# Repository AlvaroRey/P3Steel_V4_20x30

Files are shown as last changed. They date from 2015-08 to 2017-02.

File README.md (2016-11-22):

# P3Steel_V4_20x30
 
Version 4.0 (By Alvaro Rey and Daniel Torres) From P3steel by [irobri](http://www.thingiverse.com/thing:157303) with the listed changes:

* The extruder no longer hits the Z axis top bracket
* Y axis belt tensioner ( that may be placed printed or metallic )
* Weight reduction cutting as much material as possible
* Holes to bolt the PSU to the frame
* Electronics as high as possible so that the LCD cables are well hidden
* Holes in the top bracket of the Z axis to position bearing
* Holes in the top bracket of the Z axis to place spool holder
* Axis movable to lose the least footprint as posible
* Y axis uses 2020 profile, less pieces, more easy to install, less wieght, less price
* Y axis bed it's suitable to install 20x20 heated beds or 20x30 heated beds
* The hole for the motor connector has been enlarged, allowing installation of engines below 70 OZ
* Bed with option for 3 or 4 bearings
* Bed with choice of 4 or 3 leveling points
* Holes for Zip ties added to the main frame
* The Y-Axis rods have been changed, now uses 10mm rods and LM10UU lineal Bearings. We recomended to use aluminum beds for Y axis.
* We test aluminum frame too in 3mm. It works just the same
* 20x30 Frame - the Y-axis 10mm smooth rods should now be 510mm long

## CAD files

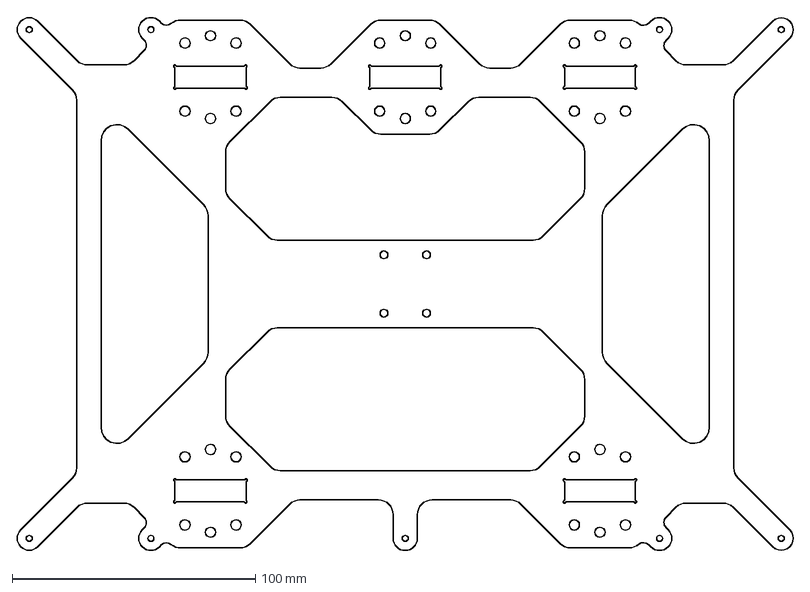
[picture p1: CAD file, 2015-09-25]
Bed_20x30_V4.DXF
319.7 x 220.0 mm

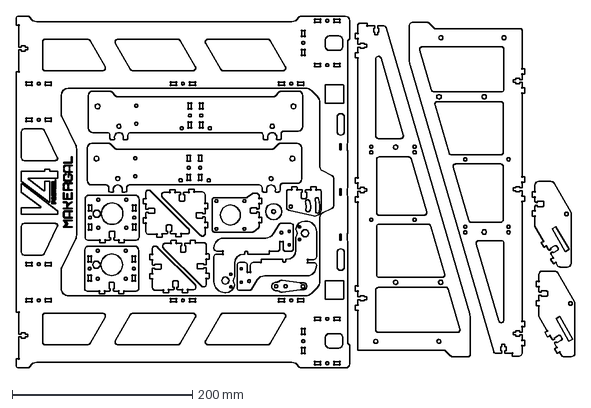
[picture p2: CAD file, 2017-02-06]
BluePrints_Planos/SEP2016/Frame_P3SteelV4_SEP2016.dxf
619.6 x 390.0 mm

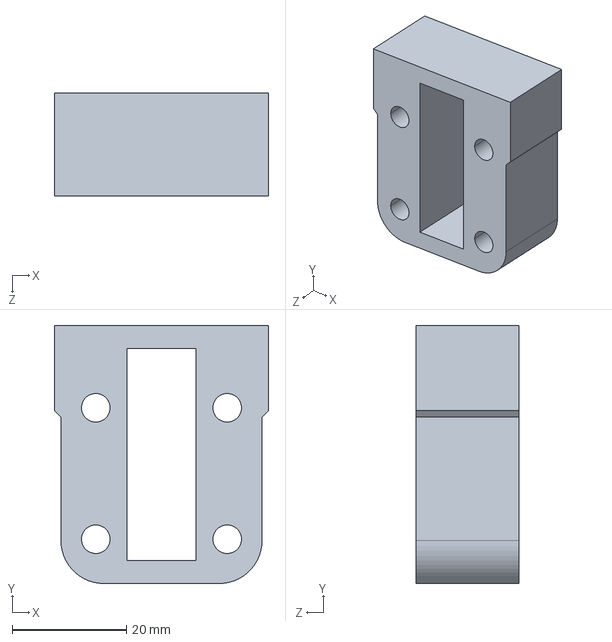
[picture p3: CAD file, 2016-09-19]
STLs/Extrusor - Separador.STEP
37.5 x 45.1 x 18.0 mm

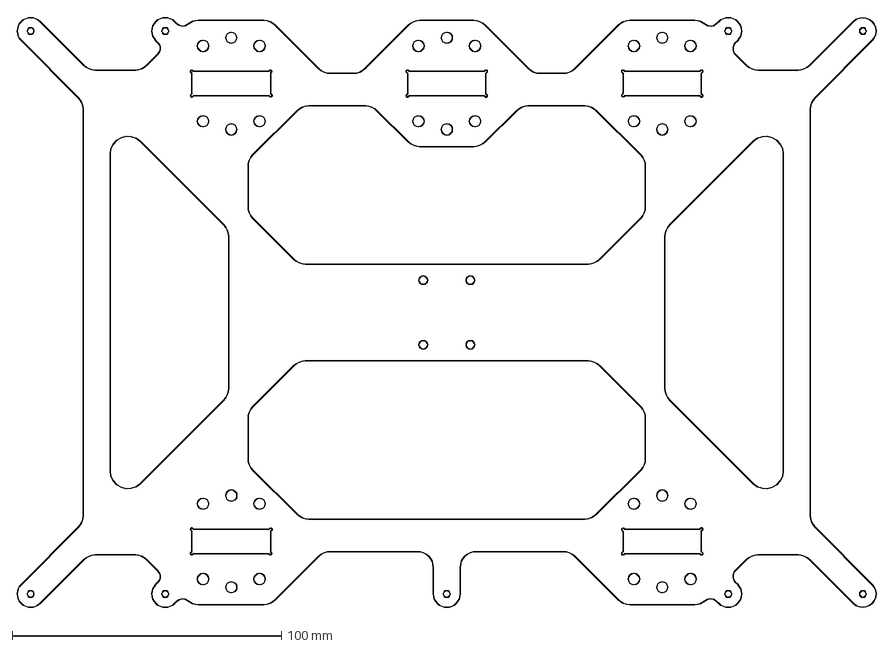
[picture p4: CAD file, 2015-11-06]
BluePrints_Planos/FEB2016/P3Steel_Bed_V4_20x30.DXF
319.7 x 220.0 mm

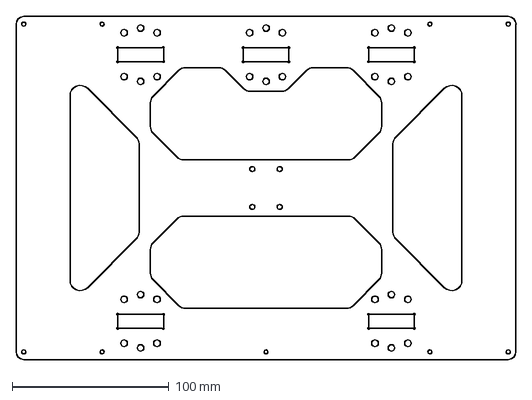
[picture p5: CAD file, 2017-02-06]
BluePrints_Planos/SEP2016/Base_P3Steel_SEP2016_ALUMINIO 4mm.DXF
318.9 x 218.9 mm

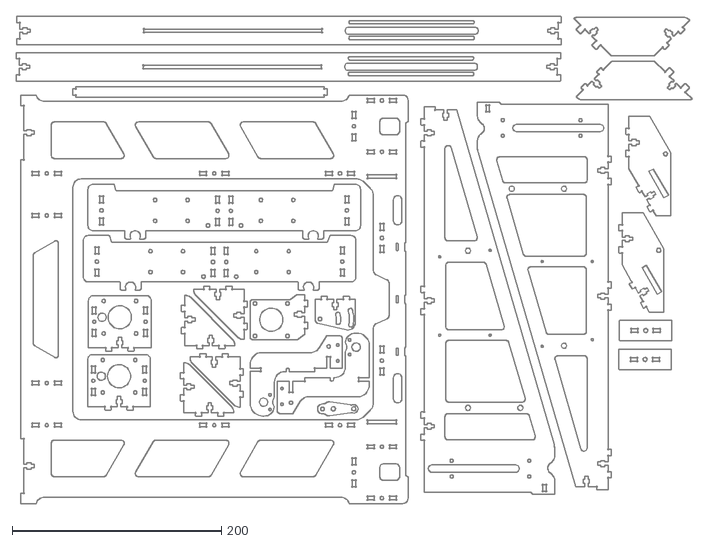
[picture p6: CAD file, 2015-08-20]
P3Steel_V4(2015)_20x30.dxf
645.5 x 465.0

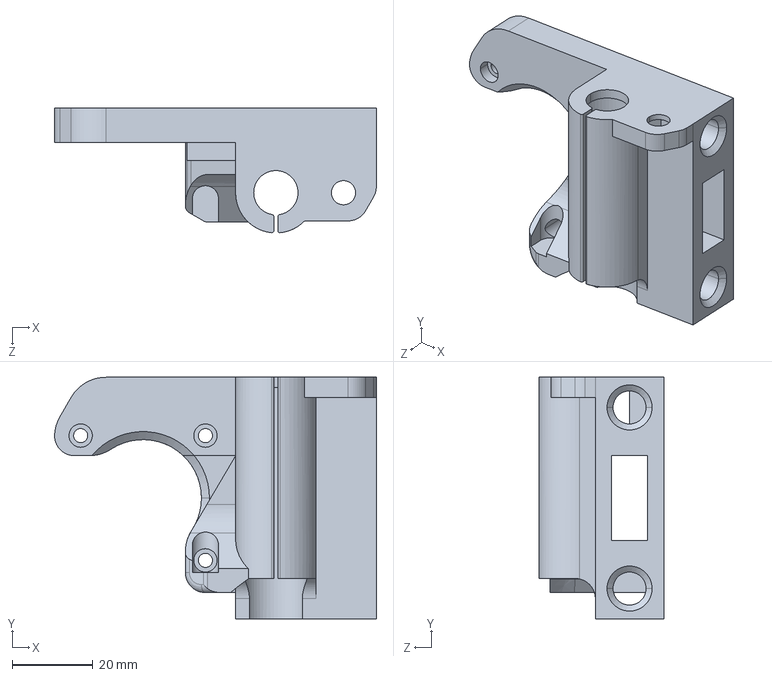
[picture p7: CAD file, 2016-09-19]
STLs/Eje X - Soporte Motor M5.STEP
80.0 x 60.0 x 30.9 mm

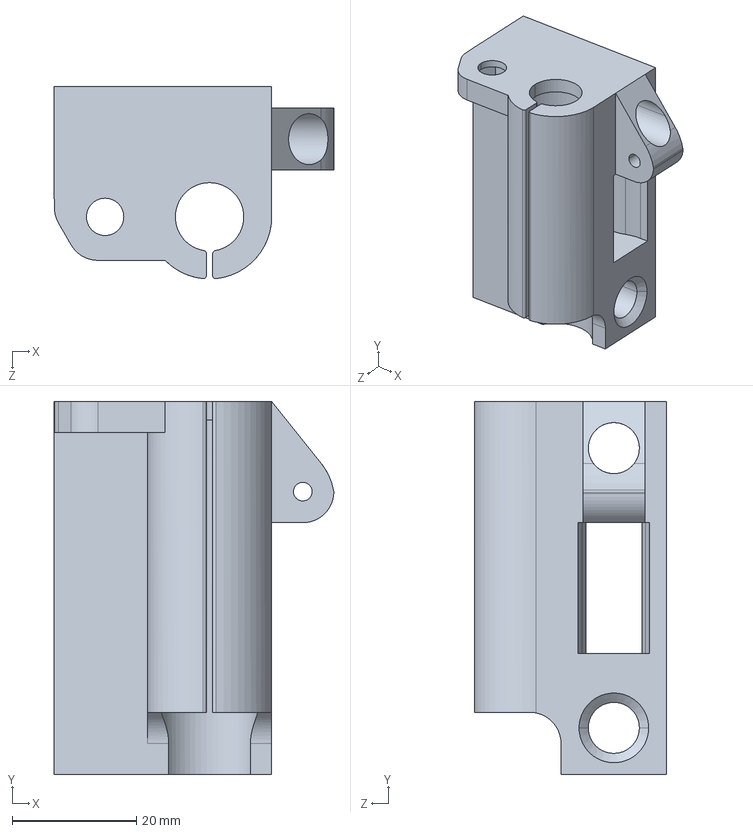
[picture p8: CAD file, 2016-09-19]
STLs/Eje X - Soporte Tensor M5.STEP
45.0 x 60.0 x 30.9 mm

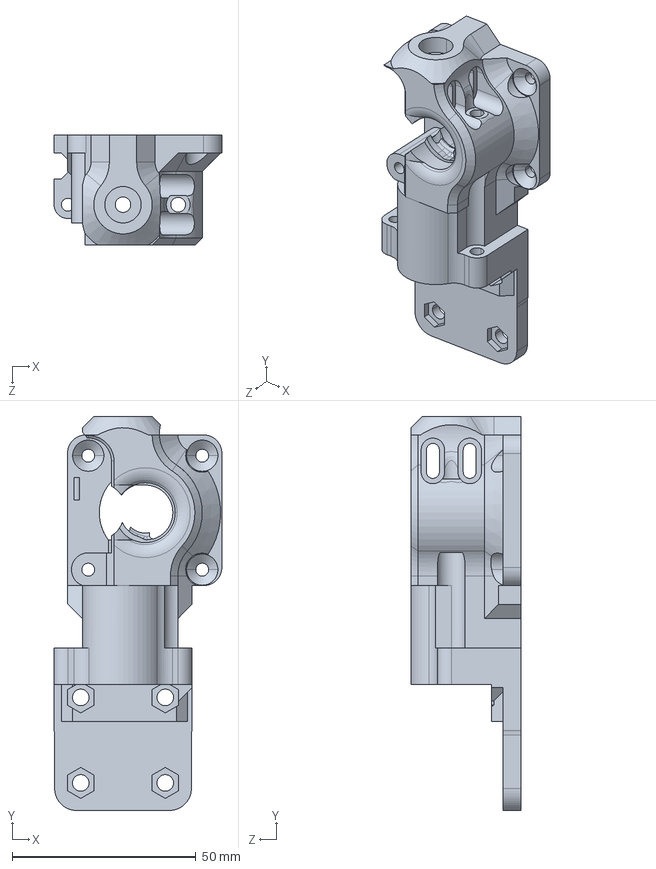
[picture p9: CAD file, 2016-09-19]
STLs/Extrusor - Cuerpo Extruder.STEP
45.7 x 107.2 x 30.0 mm

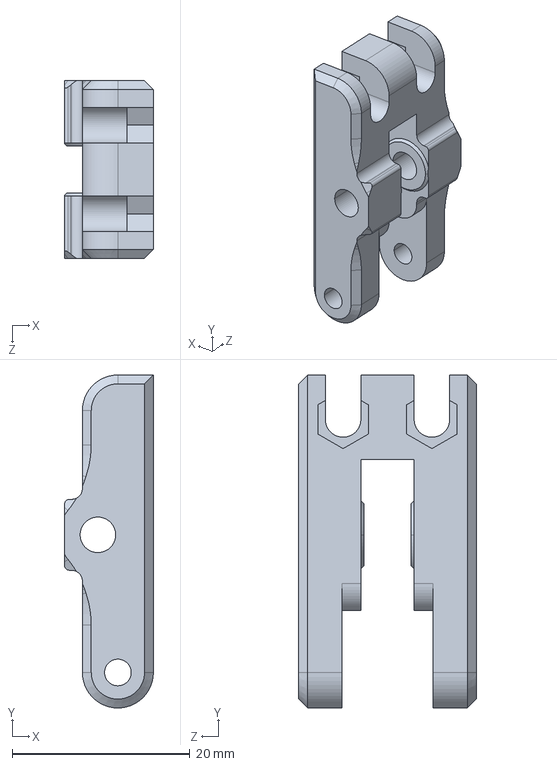
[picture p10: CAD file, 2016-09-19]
STLs/Extrusor - Tensor Filamento.STEP
10.0 x 37.5 x 20.0 mm

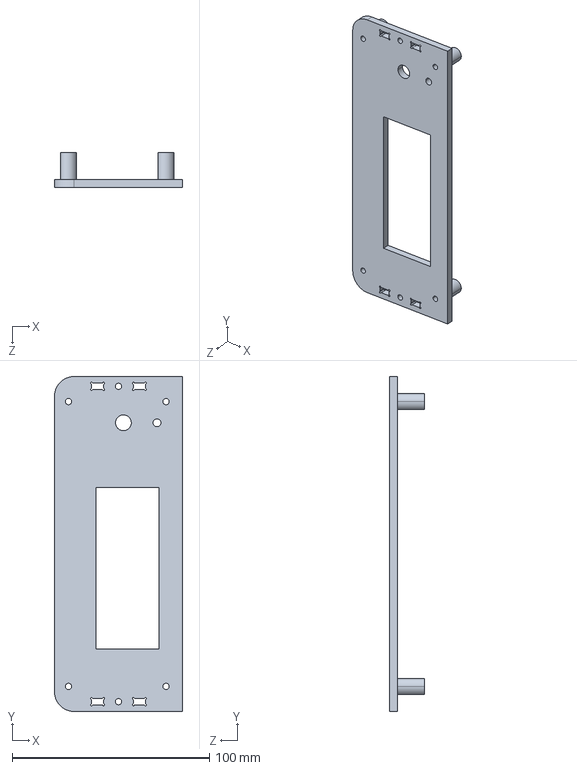
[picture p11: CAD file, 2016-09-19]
STLs/Electrónica - LCD.STEP
65.0 x 170.0 x 17.6 mm

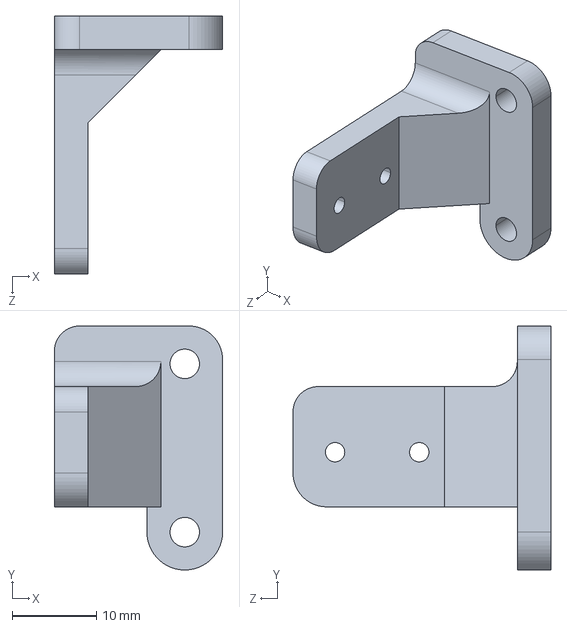
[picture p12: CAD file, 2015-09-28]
STLs/Eje Y - Soporte EndStop.STEP
20.0 x 29.0 x 30.7 mm

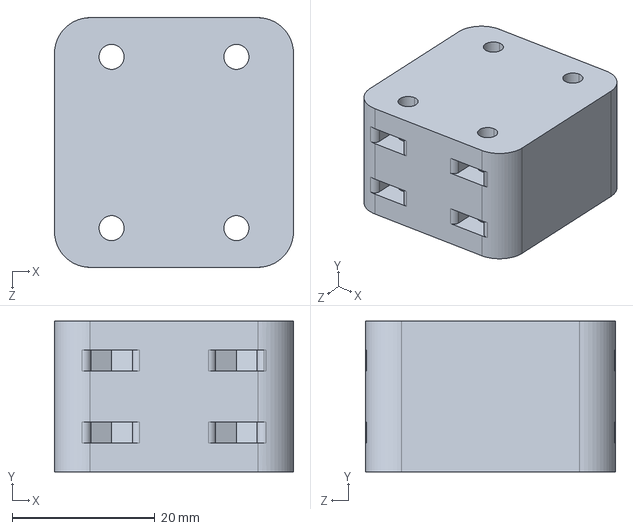
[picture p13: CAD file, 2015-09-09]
STLs/Eje Y - Enganche correa.STEP
33.5 x 21.1 x 35.0 mm

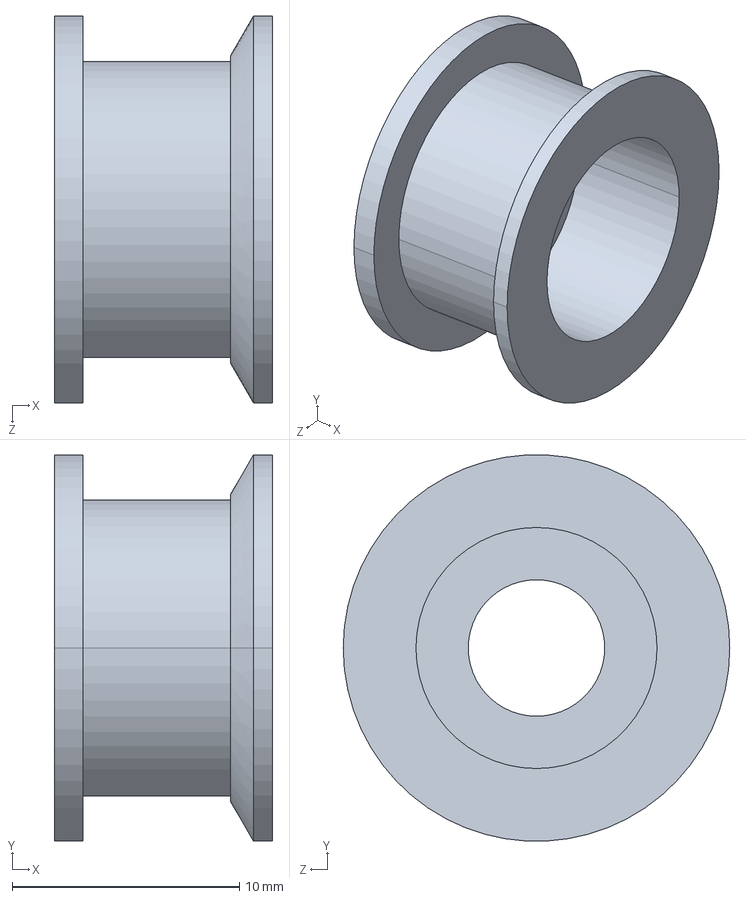
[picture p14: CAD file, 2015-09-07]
STLs/Eje X - Volanera.STEP
9.60 x 17.0 x 17.0 mm

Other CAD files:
BluePrints_Planos/FEB2016/P3Steel_Marco_V4_20x30_2016.dwg
STLs/Eje Z - Soporte EndStop.STEP
STLs/Eje X - Carro 3 Rodamientos.STL
BluePrints_Planos/FEB2016/P3Steel_Bed_V4_20x30.DWG
BluePrints_Planos/SEP2016/Base_P3Steel_SEP2016_ALUMINIO 4mm.DWG
BluePrints_Planos/SEP2016/Frame_P3SteelV4_SEP2016.dwg
STLs/Eje X - Carro 3 Rod.STEP
STLs/Eje X - Soporte Enstop.STEP
STLs/Eje X - Soporte Enstop.STL
STLs/Eje X - Soporte Motor M5.STL
STLs/Eje X - Soporte Tensor M5.STL
STLs/Eje X - Tensor Correa.STEP
STLs/Eje X - Tensor Correa.STL
STLs/Eje X - Volanera.STL
STLs/Eje Y - Eje Tensor.STEP
STLs/Eje Y - Eje Tensor.STL
STLs/Eje Y - Elevador araña LM10.STEP
STLs/Eje Y - Elevador araña LM10.STL
STLs/Eje Y - Enganche correa.STL
STLs/Eje Y - Soporte EndStop.STL
STLs/Eje Y - Tapas correa.STEP
STLs/Eje Y - Tapas correa.STL
STLs/Eje Y - Tensor correa.STEP
STLs/Eje Y - Tensor correa.STL
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

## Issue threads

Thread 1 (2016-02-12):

Please add Bill Of Materials

vuokko, 2016-02-12:
Could you add partlist to this project? Rods and bearings and their size etc.

AlvaroRey, 2016-09-28:
Threaded Rods
2x Varilla roscada M5x295 mm

Smooth Rods
2x Ø8x375 mm X axis
2x Ø10x520 mm Y axis
2x Ø8x320 mm Z axis

Bearings
2 625zz bearings
1 624zz bearings
1 623zz bearings
2 Lm8luu bearing
3 Lm8uu bearing
3 SC10uu
2 coupling
2 Gt2 20 teeth pulleys
2 meters GT2 Belt

Electronics
Arduino Mega 2560  1 unit
RAMPS 1.4      1 unit
A4988 Driver   4 units
End Stops 	3 units
Smart LCD	1 unit(Optional)
PSU 20A   1 unit (mininum)
Nema 17 70OZ   5 units

MercadoNegro, 2016-10-26:
Regarding the bill of materials, my concern is if I have to print one of each plastic parts. If not, how many of each one?

AlvaroRey, 2016-10-27:
In the name of each piece you got the numer of items you need to print
between parenthesis.

If you see no number in the piece, only print one.

Closed 2017-02-06.

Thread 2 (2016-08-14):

Unbuildable

juri74, 2016-08-14:
WARNING the designs are different than the images on internet! it appear to have missing parts and unknown parts!

https://drive.google.com/open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

AlvaroRey, 2016-08-14:
We just delete the LCD plate because it creates interferences, the rest its
in there

2016-08-14 10:54 GMT+02:00 Juri Fossaroli <notifications@github.com>:

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

--
Álvaro Rey.
alvaro.rey.rdz@gmail.com
www.makergal.es
Telf- 652 357 620

AlvaroRey, 2016-08-14:
Why you said its unbuildable??? All the pieces are in the DXF, its nothing missing.

Somethings change since we make the first frame, but little changes, nothing really important

Closed 2016-09-28.

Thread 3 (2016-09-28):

Construction?

Alex037, 2016-09-28:
Hello, could you please share an image, render, skp of the finished model (with details).
I started building this frame, and I saw that the files are updated days ago. I am using files from FEB directory. The frame itself is OK, but I am having issues with the heatbed. It seems that there is a difference that will prevent the assembled heatbed to be fit through the rods. The difference is about 3mm.

I'd appreciate any response on this, and I'd love to see it finished (with printed parts). For half of them, I cannot figure them out.

Thanks in advance

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

AlvaroRey, 2016-09-28:
I send you an STEP in order to you to check, but I make 50 frames from
older version and I dont Have problems, most of the files, for example the
first piece you show me, I didn't modify the original one, its just the
original, With the bed its similar I just modify the original desing.

https://drive.google.com/open?id=0BxUhvFbuwEAZV0kyVThDcDNMTU0

In the other hand I sell 50 frames of this one, and nobody complains about
measures, or troubles to assembly it.

And Just recheck My 3d models, and averithing has 170mm apart.

I got also a comment in github that said that its not posible to build, but
as I said a build a lot of them

Best Regards, I hope this info was helpfull

2016-09-28 18:30 GMT+02:00 Alex037 <notifications@github.com>:

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

--
Álvaro Rey.
alvaro.rey.rdz@gmail.com
www.makergal.es
Telf- 652 357 620

Alex037, 2016-09-28:
Many thanks for your fast reply. I will look into it immediately and see what is happening. I will get back to you as soon as possible.

Alex037, 2016-09-28:
Well, I did compare it to the original files from FEB and the distance is 167mm. Nevermind, I guess I will rework the two parts that hold the rods to fit them to 170mm. Could you please share several images of the completed printer with the printed STL parts attached? I'd like to see it and to figure out what is going where.

Thanks in advance.

AlvaroRey, 2016-09-28:
if you go to my website www.makergal.es , in the very bottom you will find
a button call Descargas.
You will open a dropbox folder, inside you have in the i3steel v4 a
constructiobn manual

2016-09-28 22:14 GMT+02:00 Alex037 <notifications@github.com>:

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

--
Álvaro Rey.
alvaro.rey.rdz@gmail.com
www.makergal.es
Telf- 652 357 620

Alex037, 2016-09-29:
Excellent. That will do it. Thank you very much.

AlvaroRey, 2016-09-29:
your welcome, if you assembly one plase my twitter is @makergal3d ;)

El 29 sept. 2016 9:09, "Alex037" <notifications@github.com> escribió:

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

Alex037, 2016-09-29:
Will do. I will inform you about the progress soon, this one is done with chromed steel.

AlvaroRey, 2016-09-29:
Ok thanks if you have any doubt, you know where am I

Closed 2016-09-29.

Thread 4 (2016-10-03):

Version difference

SCiunczyk, 2016-10-03:
Hola Alvaro,

I would like to build my first Prusa i3 with stainless steel frame. I wonder what is the difference between FEB2016 and SEP2016 version. What is recommended for new projects.

saludos

Slawek

AlvaroRey, 2016-10-03:
The new version use 2020 profile in the Y axis for easier assembly and
easier adjustement later

SCiunczyk, 2016-10-03:
OK,

thanks for quick answer, so the length on the 2020 profiles should be the same as "old" elements - 520mm ?

regards

Slawek

AlvaroRey, 2016-10-03:
Yes its the same lentgh its fine, it will have a little bit longer Y axis
but only a few mm

SCiunczyk, 2016-10-06:
Could you please give me some suggestions how to connect the 2020 profile to the frame. Should I use the standard corners - but I cant find mounting holes for them on main frame or maybe you are using some printed parts?

AlvaroRey, 2016-10-06:
For fixing the Y axis to the frame tou got 2 holes in each triangule, so
you fixed there, it should be enough

SCiunczyk, 2016-10-06:
Por supuesto, creo que yo era totalmente ciego.;-) Muchas gracias Alvaro y bonito dia.

AlvaroRey, 2016-10-06:
Hehehehe no pasa nada ;)

Maybe I will add a few holes for adding 2020 corners just in case someone
wants to install it

2016-10-06 10:46 GMT+02:00 SCiunczyk <notifications@github.com>:

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

--
Álvaro Rey.
alvaro.rey.rdz@gmail.com
www.makergal.es
Telf- 652 357 620

Closed 2017-02-06.

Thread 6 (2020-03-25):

Y carriage & LM8UU mounts

agrath, 2020-03-25:
Good morning,

I purchased a frame from https://orballoprinting.com/en/home/115-prusa-steel-v4-300x200-mm.html which is based on this design "with some modifications"
Unfortunately, the supplier never sent me the Y carriage plate and the bearing mounts or the spindle holder mounts.

I have followed them up over 10 times in the last 10 months and they have either not replied or said they'd send the parts which never arrive.
I have offered to pay to have them sent, or just get the cad files. Not sure if it's a translation problem or just a lack of desire to fix the problem.

I can't find any good pictures of this except in this youtube video:
https://youtu.be/akGTkkKkdA4?t=1448  and this blank (unassembled) picture https://orballoprinting.com/373-thickbox_default/prusa-steel-v4-300x200-mm.jpg

Can you advise if the design I purchased is different to the ones in this repo? I can organise to get the parts cut locally but I need the cad files, and despite asking I haven't received these either.

I know this isn't strictly to do with your design but I have no other option at this point!

blazejkarwowski, 2020-03-25:
From all i see it looks like modified version of this: https://github.com/AlvaroRey/P3Steel_V4_20x30/blob/master/BluePrints_Planos/SEP2016/Base_P3Steel_SEP2016_ALUMINIO%204mm.DWG

I would recomend geting that printed 1:1 on paper and checking if it fits.

agrath, 2020-03-26:
thanks @blazejkarwowski
it looks similar, but in the youtube video the lm8uu mounting is different (with a plate and through hole screws)
I will do the 1:1 print and start there, if the spacing is the same then this may just be good enough

agrath, 2020-03-26:
Can you also elaborate on how the LM8UU bearings mount into this plate and the belt anchor?
I am guessing some 3d printed parts which I can print on my existing printer

AlvaroRey, 2020-03-26:
Hi, yes, we use LM8uu for the Y axis bearing, and correct the Y belt
holder, it's a 3d printed piece.
For the versions question, yes is slightly different, the make they on
remix, from ours.
But my dxf should work with that frame, it's almost the same. I only modify
some pieces, but not everything.
You can print the dxt just to be shure, but any of my pieces should work
just fine with that frame

;) if you need more help, reach out bye

El jue., 26 mar. 2020 a las 7:32, agrath (<notifications@github.com>)
escribió:

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

--
Álvaro Rey.
alvaro.rey.rdz@gmail.com
www.makergal.es
Telf- 652 357 620

AlvaroRey, 2020-03-26:
I can send you also an step file of the entire machine if you want

El jue., 26 mar. 2020 a las 14:03, Álvaro Rey Rodríguez (<
alvaro.rey.rdz@gmail.com>) escribió:

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

--
Álvaro Rey.
alvaro.rey.rdz@gmail.com
www.makergal.es
Telf- 652 357 620

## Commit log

2015-05-28 DXF V4
    V4 P3steel with 20x30 Bed
    [Bed_20x30_V4.DXF, P3Steel_V4(2015)_20x30.dxf]
2015-08-20 modification
    After recibe the first frame, we change a few things wrong
    [Bed_20x30_V4.DXF, P3Steel_V4(2015)_20x30.dxf]
2015-09-07 STL y STEPs
    Printed Parts from P3Steel V4
    [Eje X - Carro 3 Rod.STEP, Eje X - Carro 3 Rodamientos.STL, Eje X - Soporte Enstop.STEP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]
2015-09-09 modificación pieza enganche correa
    modificación pieza enganche correa
    [Eje Y - Enganche correa.STEP, Eje Y - Enganche correa.STL]
2015-09-25 midifcacion base cama caliente
    Fallo en medidas SC10uu
    [Bed_20x30_V4.DXF]
2015-09-28 cambios Endstop eje Y
    [Bed_20x30_V4_Final.DWG, Bed_20x30_V4_Final.DXF, Eje Y - Soporte EndStop.STEP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]
2015-11-06 modficacion final
    ultimos ajustes del marco
    [Bed_20x30_V4_Final.DWG, Bed_20x30_V4_Final.DXF, P3Steel_V4(2015)_20x30_Final.dwg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]
2015-11-09 cambio
    cambio
    [Bed_20x30_V4_Final.DWG, Bed_20x30_V4_Final.DXF, P3Steel_V4(2015)_20x30_FinalFinal.dwg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]
2016-06-02 Versión 2016
    realizados algunos cambios en redondeos y recortes para facilitar el
    corte del mismo mediante láser
    [Bed_20x30_V4_Final.DWG, Bed_20x30_V4_Final.DXF, P3Steel_Bed_V4_20x30.DWG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]
2016-09-19 Changes September 2016
    The Y Axis changes, now the Y axis uses 2020 profile, the structure is a
    little bit stiffer, thank to that we can remove 7 steel pieces.
    [Base_P3Steel_SEP2016.DWG, Base_P3Steel_SEP2016.DXF, Eje X - Carro 3 Rod.STEP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]
2017-02-06 Little Changes
    Adjustments, in hole measure, to ensure a proper assembly
    [Base_P3Steel_SEP2016_ALUMINIO 4mm.DWG, Base_P3Steel_SEP2016_ALUMINIO 4mm.DXF, Frame_P3SteelV4_SEP2016.dwg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]
2017-02-13 Update DWG files, to the new version
    The changes were not applied to the dwg files
    [Base_P3Steel_SEP2016_ALUMINIO 4mm.DWG, Frame_P3SteelV4_SEP2016.dwg]
2017-02-13 wrong file
    wrong file
    [Base_P3Steel_SEP2016.DWG]
2017-07-21 Piezas finales, sin errores
    Corrección de pequeños errores de diseño
    [Base_P3Steel_SEP2016_ALUMINIO 4mm.DWG, Frame_P3SteelV4_SEP2016.dwg]
2017-07-21 Marco final sin errores
    Despiece corregido, al igual que los ficheros conjuntos
